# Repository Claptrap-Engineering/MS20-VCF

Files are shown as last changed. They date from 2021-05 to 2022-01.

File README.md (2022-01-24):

# MS20-VCF
6HP eurorack SMD version of the famous MS20 Voltage controlled filter.

Based on the work of other community members as René Schmitz, Look Mum No Computer, Eddy Bergman, KORG and many others.

You can find the mouser bom here (you might want to add the desired potmeters).
https://www.mouser.com/ProjectManager/ProjectDetail.aspx?AccessID=ca94445cf4

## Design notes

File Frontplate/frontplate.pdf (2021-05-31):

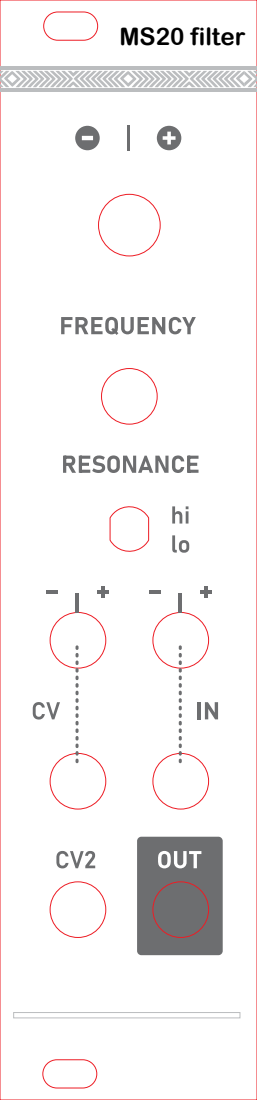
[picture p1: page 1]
MS20 filter

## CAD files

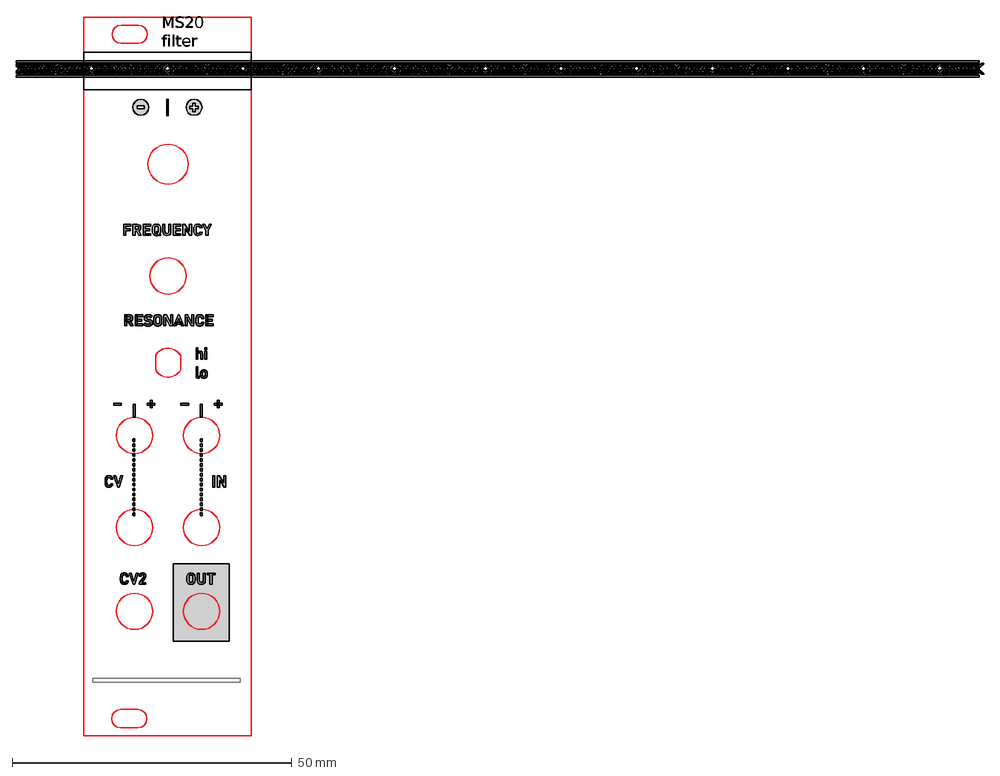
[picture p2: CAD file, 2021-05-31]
Frontplate/frontplate.dxf
MS20 filter

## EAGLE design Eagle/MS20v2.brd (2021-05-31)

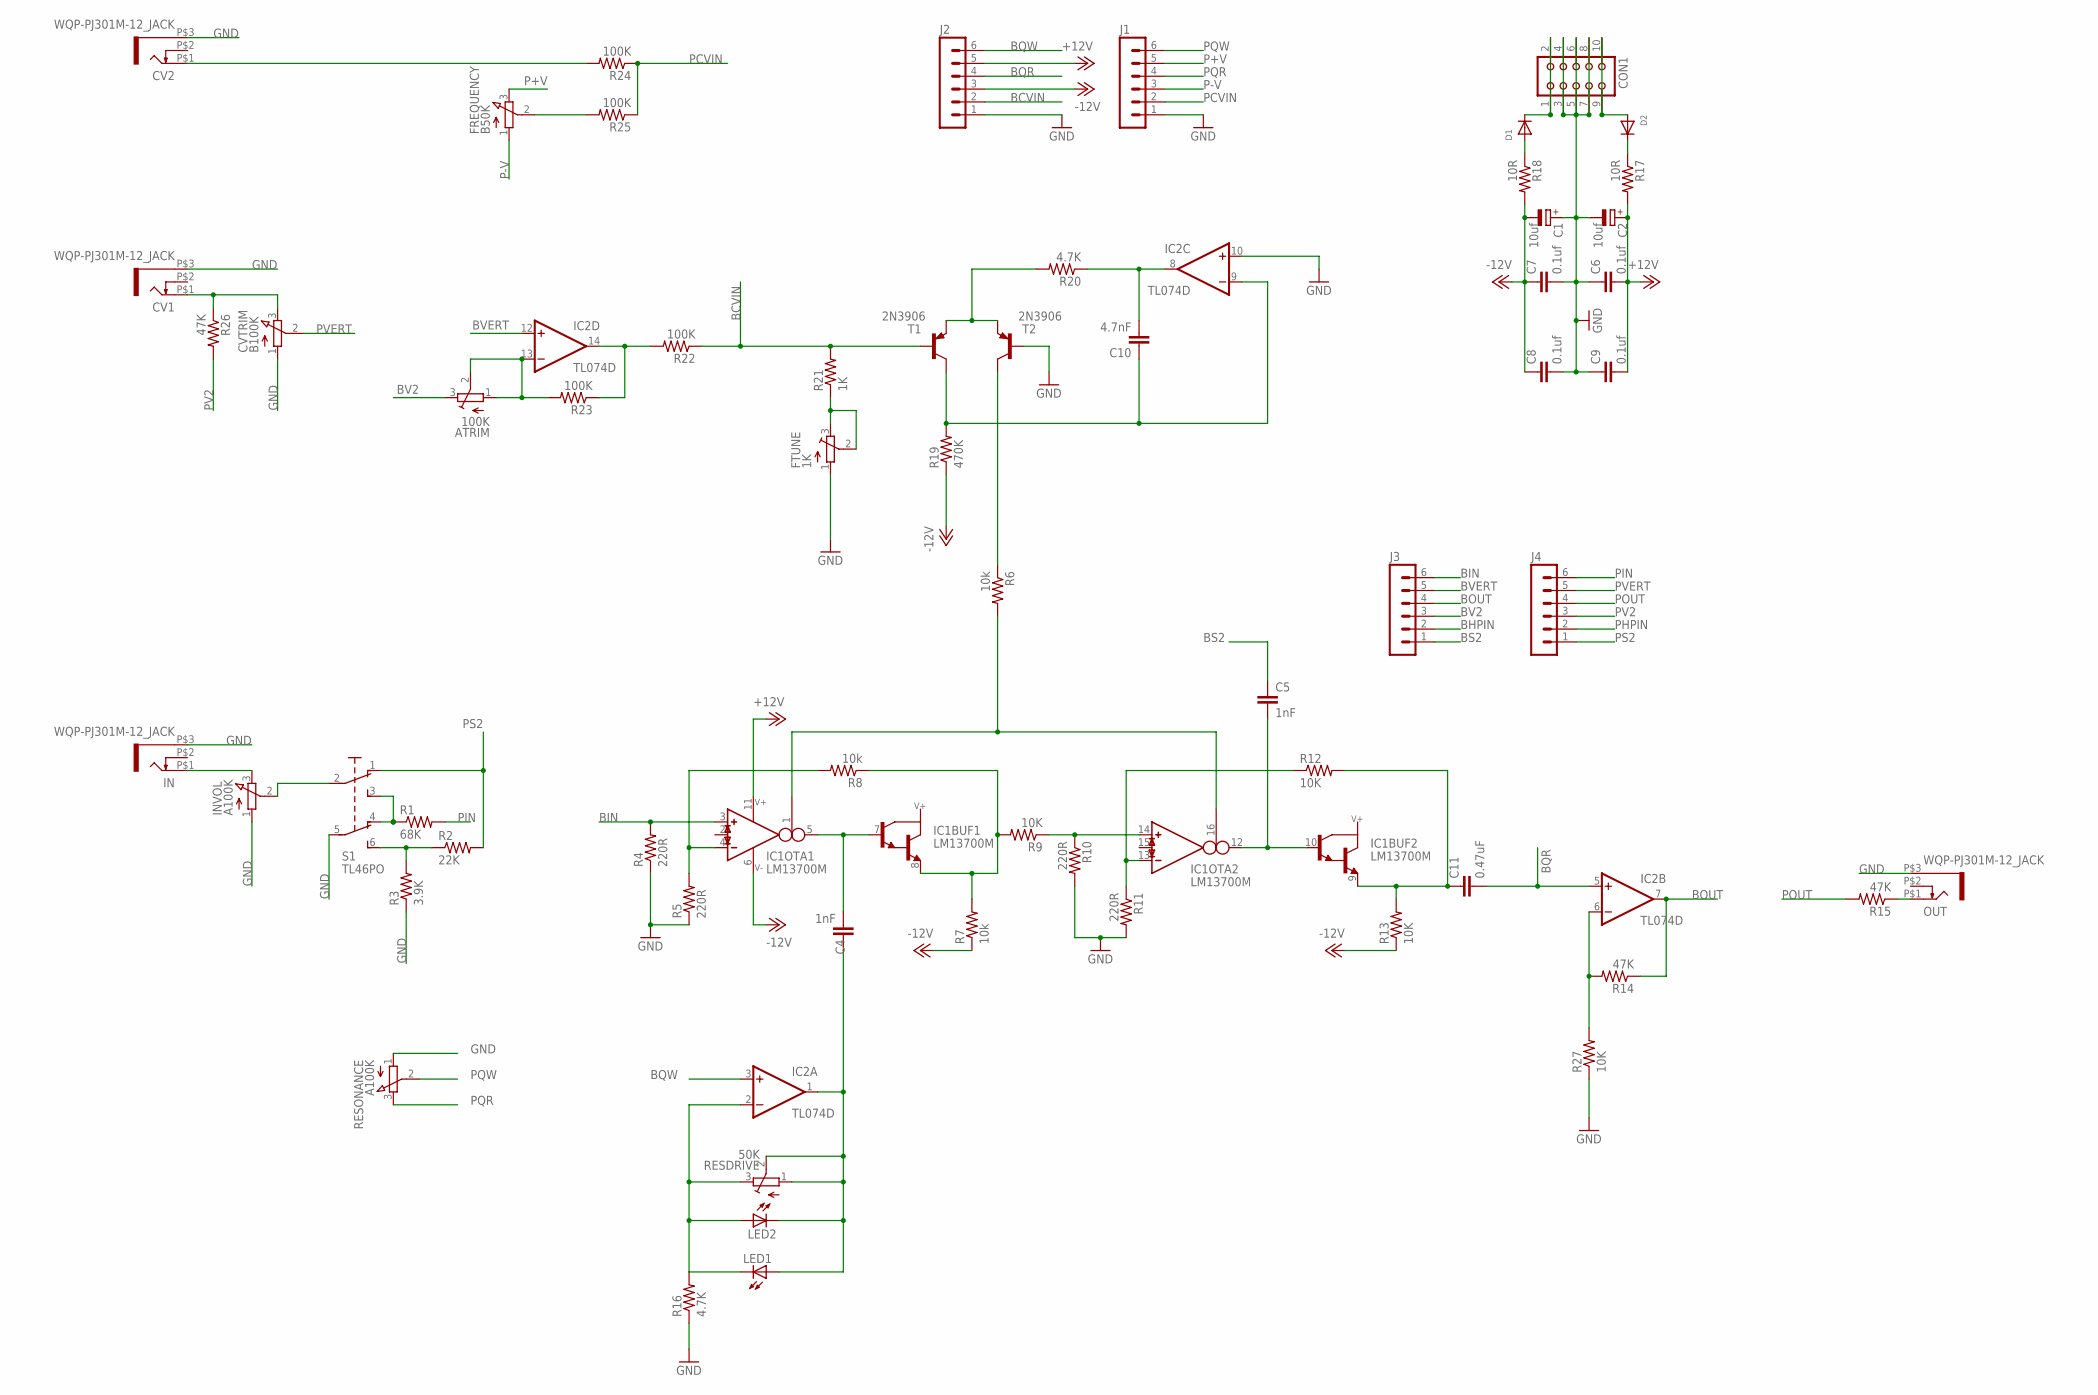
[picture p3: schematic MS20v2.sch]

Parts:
ATRIM: 100K; TC33X
C1, C2: 10uf; 153CLV-0405
C4, C5: 1nF; C0603
C6, C7, C8, C9: 0.1uf; C0603
C10: 4.7nF; C0603
C11: 0.47uF; C0603
CON1: CON10
CV1, CV2: WQP-PJ301M-12_JACK
CVTRIM: B100K; EVUF
D1, D2: DIODESOD-123; SOD-123
FREQUENCY: B50K; EVUF
FTUNE: 1K; TC33X
IC1: LM13700M; SO16
IC2: TL074D; SO14
IN: WQP-PJ301M-12_JACK
INVOL: A100K; EVUF
J1, J2, J3, J4: MA06-1
LED1, LED2: LED3MM
OUT: WQP-PJ301M-12_JACK
R1: 68K; R0603
R2: 22K; R0603
R3: 3.9K; R0603
R4, R5, R10, R11: 220R; R0603
R6, R7, R8: 10k; R0603
R9, R12, R13, R27: 10K; R0603
R14, R15, R26: 47K; R0603
R16, R20: 4.7K; R0603
R17, R18: 10R; R0603
R19: 470K; R0603
R21: 1K; R0603
R22, R23, R24, R25: 100K; R0603
RESDRIVE: 50K; TC33X
RESONANCE: A100K; EVUF
S1: TL46PO; TL4XPO
T1, T2: 2N3906; SOT23-BEC

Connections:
+12V: C2.+, C6.2, C9.2, IC1.11 (V+), IC2.4 (V+), J2.5, R17.2
-12V: C1.-, C7.1, C8.1, IC1.6 (V-), IC2.11 (V-), J2.3, R7.1, R13.1, R18.2, R19.1
BCVIN: J2.2, R21.2, R22.1, T1.B
BHPIN: J3.2
BIN: IC1.3 (IN_P), J3.6, R4.2
BOUT: IC2.7 (OUT), J3.4, R14.1
BQR: C11.2, IC2.5 (+IN), J2.4
BQW: IC2.3 (+IN), J2.6
BS2: C5.1, J3.1
BV2: ATRIM.3 (E), J3.3
BVERT: IC2.12 (+IN), J3.5
GND: C1.+, C2.-, C6.1, C7.2, C8.2, C9.1, CON1.3, CON1.4, CON1.5, CON1.6, CON1.7, CON1.8, CV1.P$3 (1), CV2.P$3 (1), CVTRIM.1 (A), FTUNE.1 (A), IC2.10 (+IN), IN.P$3 (1), INVOL.1 (A), J1.1, J2.1, OUT.P$3 (1), R3.1, R4.1, R5.1, R10.2, R11.2, R16.1, R27.1, RESONANCE.1 (A), S1.5 (P1), T2.B
unnamed: CON1.9, CON1.10, D2.A
unnamed: CON1.1, CON1.2, D1.C
unnamed: R1.1, S1.3 (S), S1.4 (O1)
unnamed: R2.1, R3.2, S1.6 (S1)
unnamed: D1.A, R18.1
unnamed: IC1.4 (IN_N), R5.2, R8.2
unnamed: CV1.P$1 (2), CVTRIM.3 (E), R26.1
unnamed: D2.C, R17.1
unnamed: IC1.13 (IN_N), R11.1, R12.1
unnamed: IC1.8 (E), R7.2, R8.1, R9.2
unnamed: C4.2, IC1.5 (OUT), IC1.7 (B)
unnamed: IC1.1 (I_BIAS), IC1.16 (I_BIAS), R6.2
unnamed: IC2.14 (OUT), R22.2, R23.1
unnamed: C4.1, IC2.1 (OUT), LED1.A, LED2.K (C), RESDRIVE.1 (A), RESDRIVE.2 (S)
unnamed: IC1.14 (IN_P), R9.1, R10.1
unnamed: C11.1, IC1.9 (E), R12.2, R13.2
unnamed: C5.2, IC1.10 (B), IC1.12 (OUT)
unnamed: IC2.6 (-IN), R14.2, R27.2
unnamed: R6.1, T2.C
unnamed: R20.2, T1.E, T2.E
unnamed: C10.2, IC2.8 (OUT), R20.1
unnamed: C10.1, IC2.9 (-IN), R19.2, T1.C
unnamed: IC2.2 (-IN), LED1.K (C), LED2.A, R16.2, RESDRIVE.3 (E)
unnamed: FTUNE.2 (S), FTUNE.3 (E), R21.1
unnamed: ATRIM.1 (A), ATRIM.2 (S), IC2.13 (-IN), R23.2
unnamed: CV2.P$1 (2), R24.2
unnamed: INVOL.2 (S), S1.2
unnamed: IN.P$1 (2), INVOL.3 (E)
unnamed: FREQUENCY.2 (S), R25.2
unnamed: OUT.P$1 (2), R15.1
P+V: FREQUENCY.3 (E), J1.5
P-V: FREQUENCY.1 (A), J1.3
PCVIN: J1.2, R24.1, R25.1
PHPIN: J4.2
PIN: J4.6, R1.2
POUT: J4.4, R15.2
PQR: J1.4, RESONANCE.3 (E)
PQW: J1.6, RESONANCE.2 (S)
PS2: J4.1, R2.2, S1.1 (O)
PV2: J4.3, R26.2
PVERT: CVTRIM.2 (S), J4.5

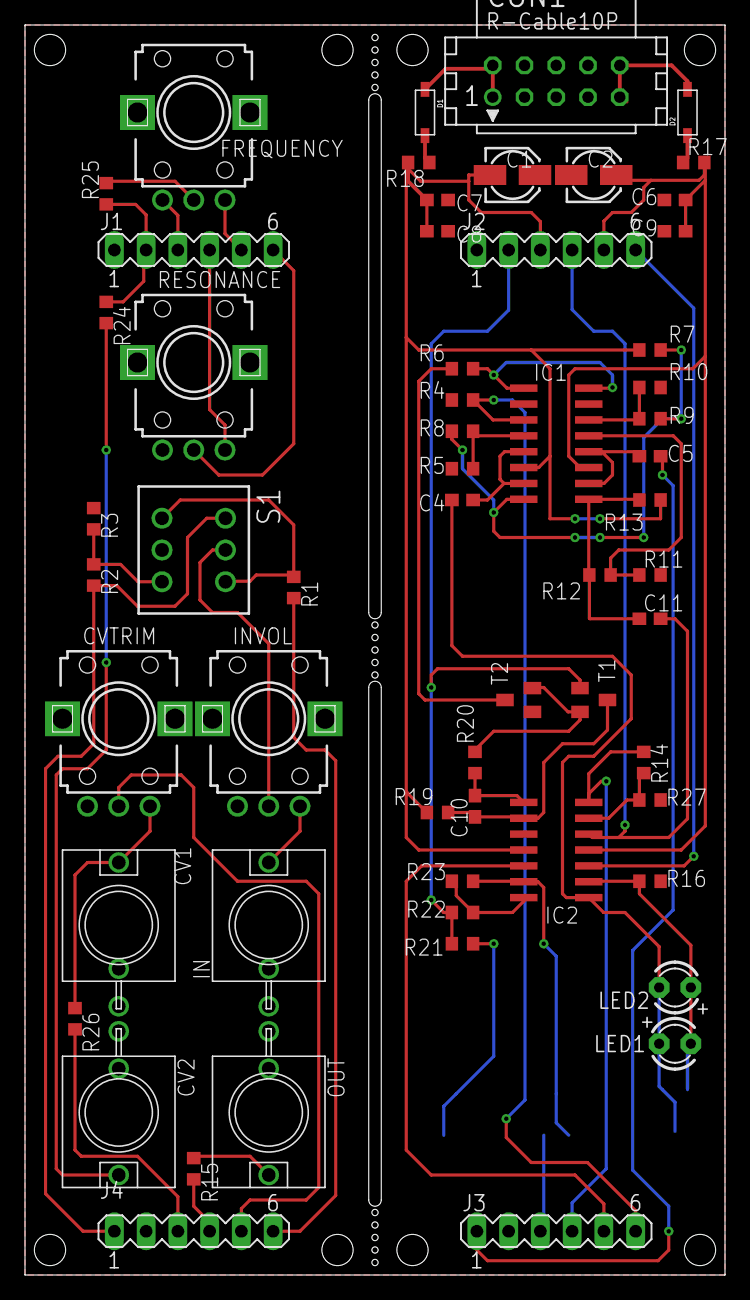
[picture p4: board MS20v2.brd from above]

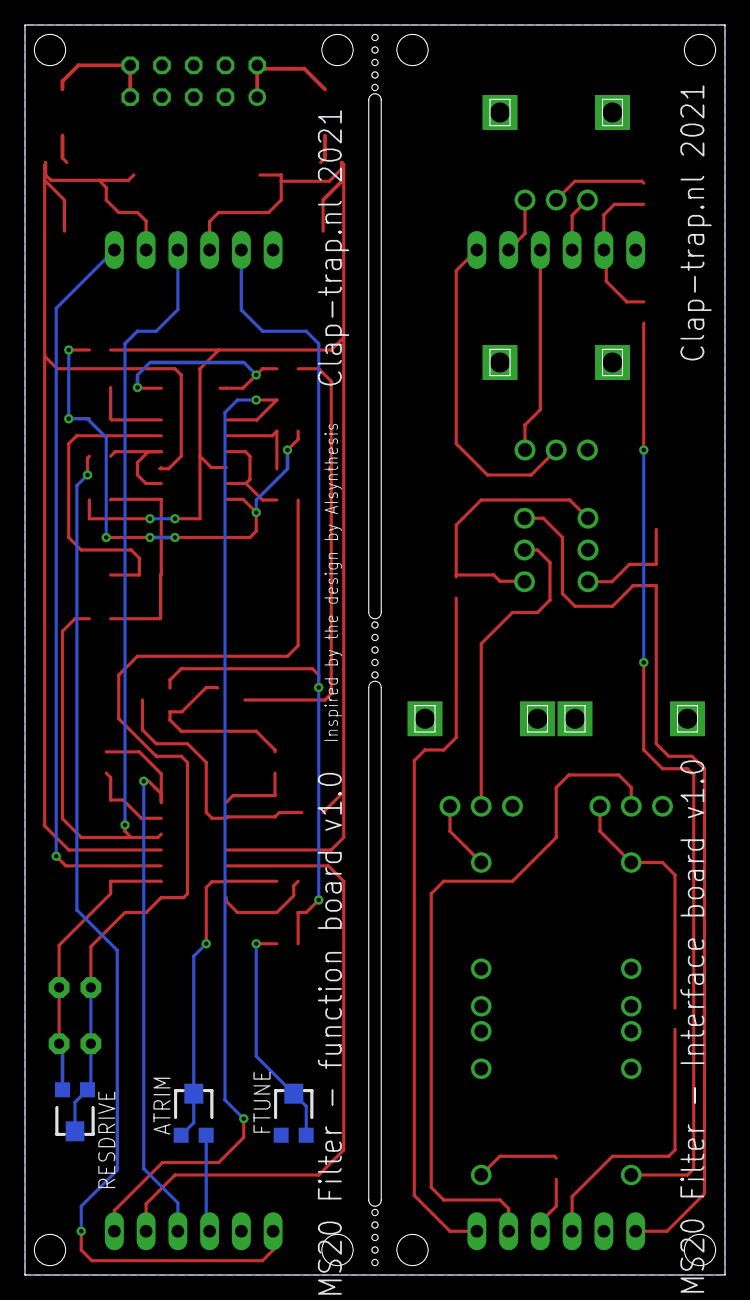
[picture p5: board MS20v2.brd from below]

Board: 2 copper layers, 56.0 x 100.0 mm, 62 parts (3 on the bottom side), 51 nets.

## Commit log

2021-04-30 first push
    [MS20v2.brd, MS20v2.sch]
2021-05-26 updated drawing for readability
    [MS20v2.brd, MS20v2.sch]
2021-05-26 updated Pot designations/values
    [MS20v2.brd, MS20v2.sch]
2021-05-26 changed HP/LP switch type to TL46 P0
    [MS20v2.brd, MS20v2.sch]
2021-05-31 front plate files
2021-05-31 exported frontplate files
    [frontplate.dxf]
2021-05-31 Changed 10uf cap to 0,47uf cap
    [MS20v2.brd, MS20v2.sch]
